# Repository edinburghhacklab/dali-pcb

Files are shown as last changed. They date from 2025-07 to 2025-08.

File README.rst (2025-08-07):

DALI PCB
========

Overview
--------

PCB to power and interface with DALI using an ESP32-S3.

Dimensions: 100mm W × 75mm H

Usage
-----

This is a KiCad project.

* `Software <https://github.com/edinburghhacklab/mqtt-dali-controller>`_

Schematics
----------

Power for the DALI bus is optional and can be connected using the solder jumper
bridges. If the power is supplied by this PCB then the polarity of the bus is
fixed so the bridge rectifier can be omitted.

Root schematic

DALI
~~~~

There are 2 DALI bus connections.

DALI schematic

Power
~~~~~

Power for the DALI bus is supplied by an external 12-22V DC power supply. Power
for the microcontroller is supplied by USB to the development board or an
external 5V DC power supply.

Power schematic

Microcontroller
~~~~~~~~~~~~~~~

Connect a `LOLIN S3  <https://www.wemos.cc/en/latest/s3/s3.html>`_ development
board to the pin sockets.

Microcontroller schematic

I/O
~~~

Analogue and digital I/O pin headers are provided for integrations with external
switches and rotary encoders.

The DALI bus also has a 3.3V direct pin header which can only be used when the
microcontroller is disconnected. This can't be used with a standard UART because
the DALI communication uses Manchester (bi-phase) encoding.

I/O schematic

PCB
---

* Internal bus power: populate JP1-2, and populate either JP3-4 or D5
* External bus power: populate D5, do not populate JP1-4

DALI PCB

Components
----------

+---------------------+----------+--------------------------------------------------------+
| Refs                | Quantity | Name                                                   |
+=====================+==========+========================================================+
|                     |     1    | LOLIN S3 Development Board                             |
+---------------------+----------+--------------------------------------------------------+
| D3                  |     1    | Diodes BAV99-7-F Dual Switching Diode, SOT-23-3        |
+---------------------+----------+--------------------------------------------------------+
| D4                  |     1    | Diodes DDZ9689S-7 Zener Diode, SOD-323                 |
+---------------------+----------+--------------------------------------------------------+
| D5                  |     1    | Infineon BGX50AE6327 Diode Bridge, SOT-143             |
+---------------------+----------+--------------------------------------------------------+
| J1, J2, J3, J4      |     4    | 1x02 Terminal Block, Through Hole (5.08mm)             |
+---------------------+----------+--------------------------------------------------------+
| J5, J6              |     2    | 1x20 Pin Socket, Through Hole (2.54mm)                 |
+---------------------+----------+--------------------------------------------------------+
| J7                  |     1    | 1x04 Pin Header, Through Hole (2.54mm)                 |
+---------------------+----------+--------------------------------------------------------+
| J8, J9              |     2    | 2x13 Pin Header, Through Hole (2.54mm)                 |
+---------------------+----------+--------------------------------------------------------+
| Q1                  |     1    | ON Semiconductor PZT2222AT1G NPN Transistor, SOT-223   |
+---------------------+----------+--------------------------------------------------------+
| Q2                  |     1    | ON Semiconductor MMBT2222ALT1G NPN Transistor, SOT-23  |
+---------------------+----------+--------------------------------------------------------+
| R2                  |     1    | 12Ω 1W Resistor, SMD 2512 (Metric 6332)                |
+---------------------+----------+--------------------------------------------------------+
| R3, R8              |     2    | 1kΩ 1W Resistor, SMD 2512 (Metric 6332)                |
+---------------------+----------+--------------------------------------------------------+
| R4                  |     1    | 120Ω 125mW Resistor, SMD 0805 (Metric 2012)            |
+---------------------+----------+--------------------------------------------------------+
| R5                  |     1    | 220Ω 125mW Resistor, SMD 0805 (Metric 2012)            |
+---------------------+----------+--------------------------------------------------------+
| R6                  |     1    | 2.2kΩ 250mW Resistor, SMD 1206 (Metric 3216)           |
+---------------------+----------+--------------------------------------------------------+
| R7                  |     1    | 10kΩ 125mW Resistor, SMD 0805 (Metric 2012)            |
+---------------------+----------+--------------------------------------------------------+
| U1, U2              |     2    | Vishay Semiconductors TCLT1000 Optocoupler, SOP-4L     |
+---------------------+----------+--------------------------------------------------------+

Total pin header count: 56

References
----------

* `Digitally Addressable Lighting Interface (DALI) Communication <https://ww1.microchip.com/downloads/en/AppNotes/01465A.pdf>`_

* `Digitally Addressable Lighting Interface (DALI) Unit Using the MC68HC908KX8 <https://www.nxp.com/docs/en/reference-manual/DRM004.pdf>`_

* `Digital Addressable Lighting Interface (DALI) Implementation Using MSP430 Value Line Microcontrollers <https://www.ti.com/lit/an/slaa422a/slaa422a.pdf>`_

* `DALI Communication Using the EFR32 <https://www.silabs.com/documents/public/application-notes/an1220-efr32-dali.pdf>`_

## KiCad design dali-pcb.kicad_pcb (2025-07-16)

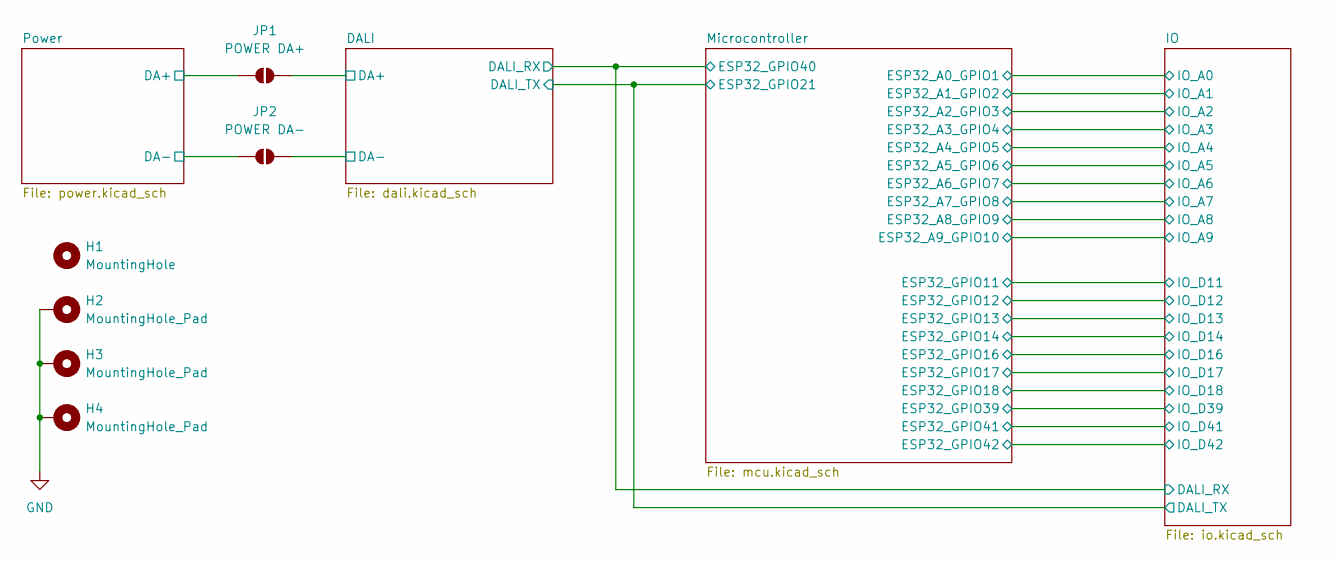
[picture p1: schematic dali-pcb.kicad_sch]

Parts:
H1: MountingHole; MountingHole_3.2mm_M3
H2, H3, H4: MountingHole_Pad; MountingHole_3.2mm_M3_Pad
JP1: POWER DA+; SolderJumper-2_P1.3mm_Open_RoundedPad1.0x1.5mm
JP2: POWER DA-; SolderJumper-2_P1.3mm_Open_RoundedPad1.0x1.5mm

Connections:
/DALI/DA+: JP1.1 (A); also elsewhere on the board
/DALI/DA-: JP2.2 (B); also elsewhere on the board
/Power/DA+: JP1.2 (B); also elsewhere on the board
/Power/DA-: JP2.1 (A); also elsewhere on the board
GND: H2.1, H3.1, H4.1; also elsewhere on the board

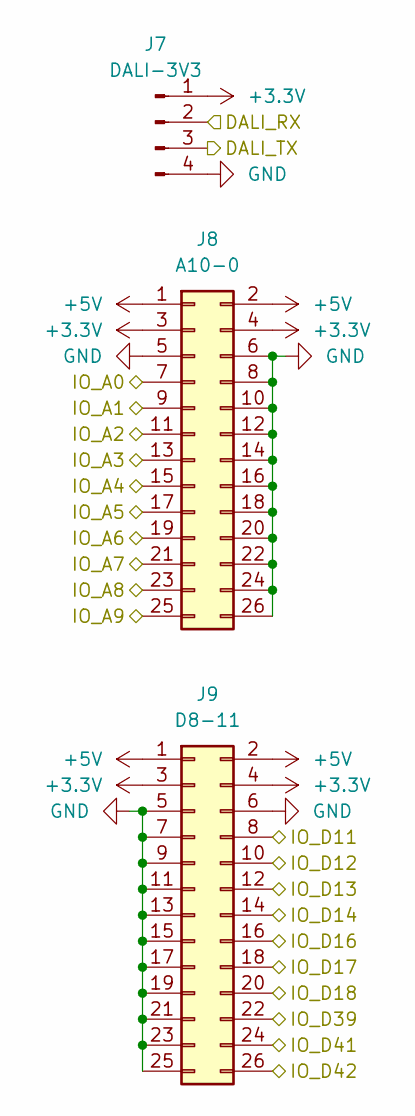
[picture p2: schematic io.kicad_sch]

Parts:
J7: DALI-3V3; PinHeader_1x04_P2.54mm_Vertical
J8: A10-0; PinHeader_2x13_P2.54mm_Vertical
J9: D8-11; PinHeader_2x13_P2.54mm_Vertical

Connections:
+3.3V: J7.1, J8.3, J8.4, J9.3, J9.4; also elsewhere on the board
+5V: J8.1, J8.2, J9.1, J9.2; also elsewhere on the board
/DALI/DALI_RX: J7.2; also elsewhere on the board
/DALI/DALI_TX: J7.3; also elsewhere on the board
/IO/IO_A0: J8.7; also elsewhere on the board
/IO/IO_A1: J8.9; also elsewhere on the board
/IO/IO_A2: J8.11; also elsewhere on the board
/IO/IO_A3: J8.13; also elsewhere on the board
/IO/IO_A4: J8.15; also elsewhere on the board
/IO/IO_A5: J8.17; also elsewhere on the board
/IO/IO_A6: J8.19; also elsewhere on the board
/IO/IO_A7: J8.21; also elsewhere on the board
/IO/IO_A8: J8.23; also elsewhere on the board
/IO/IO_A9: J8.25; also elsewhere on the board
/IO/IO_D11: J9.8; also elsewhere on the board
/IO/IO_D12: J9.10; also elsewhere on the board
/IO/IO_D13: J9.12; also elsewhere on the board
/IO/IO_D14: J9.14; also elsewhere on the board
/IO/IO_D16: J9.16; also elsewhere on the board
/IO/IO_D17: J9.18; also elsewhere on the board
/IO/IO_D18: J9.20; also elsewhere on the board
/IO/IO_D39: J9.22; also elsewhere on the board
/IO/IO_D41: J9.24; also elsewhere on the board
/IO/IO_D42: J9.26; also elsewhere on the board
GND: J7.4, J8.5, J8.6, J8.8, J8.10, J8.12, J8.14, J8.16, J8.18, J8.20, J8.22, J8.24, J8.26, J9.5, J9.6, J9.7, J9.9, J9.11, J9.13, J9.15, J9.17, J9.19, J9.21, J9.23, J9.25; also elsewhere on the board

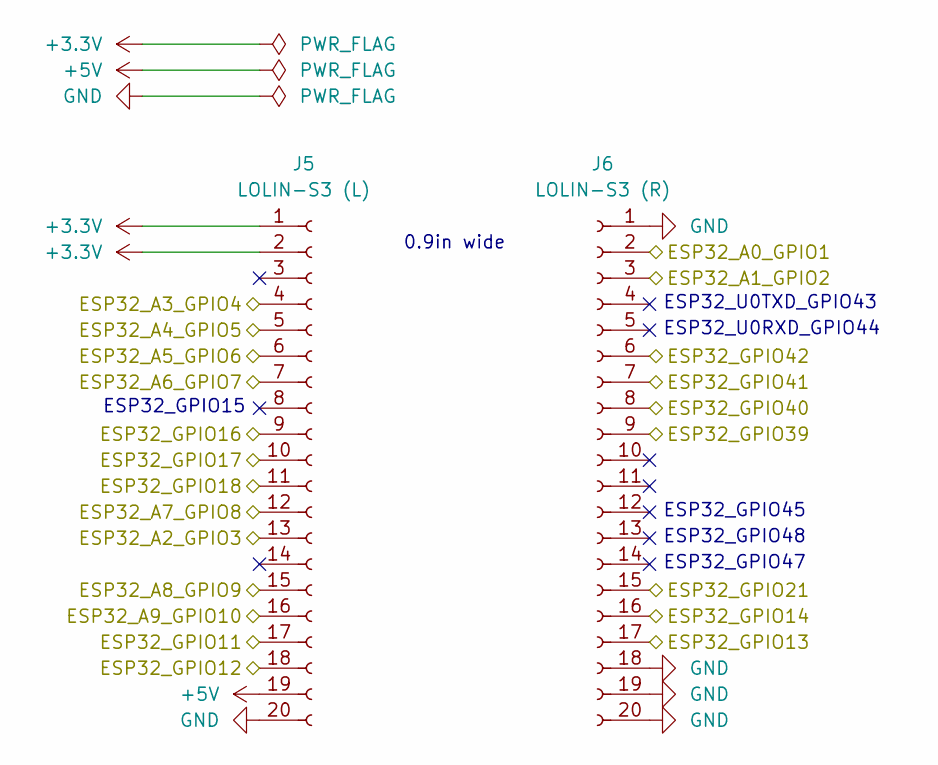
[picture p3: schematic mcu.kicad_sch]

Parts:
J5: LOLIN-S3 (L); PinSocket_1x20_P2.54mm_Vertical
J6: LOLIN-S3 (R); PinSocket_1x20_P2.54mm_Vertical

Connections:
+3.3V: J5.1, J5.2; also elsewhere on the board
+5V: J5.19; also elsewhere on the board
/DALI/DALI_RX: J6.8; also elsewhere on the board
/DALI/DALI_TX: J6.15; also elsewhere on the board
/IO/IO_A0: J6.2; also elsewhere on the board
/IO/IO_A1: J6.3; also elsewhere on the board
/IO/IO_A2: J5.13; also elsewhere on the board
/IO/IO_A3: J5.4; also elsewhere on the board
/IO/IO_A4: J5.5; also elsewhere on the board
/IO/IO_A5: J5.6; also elsewhere on the board
/IO/IO_A6: J5.7; also elsewhere on the board
/IO/IO_A7: J5.12; also elsewhere on the board
/IO/IO_A8: J5.15; also elsewhere on the board
/IO/IO_A9: J5.16; also elsewhere on the board
/IO/IO_D11: J5.17; also elsewhere on the board
/IO/IO_D12: J5.18; also elsewhere on the board
/IO/IO_D13: J6.17; also elsewhere on the board
/IO/IO_D14: J6.16; also elsewhere on the board
/IO/IO_D16: J5.9; also elsewhere on the board
/IO/IO_D17: J5.10; also elsewhere on the board
/IO/IO_D18: J5.11; also elsewhere on the board
/IO/IO_D39: J6.9; also elsewhere on the board
/IO/IO_D41: J6.7; also elsewhere on the board
/IO/IO_D42: J6.6; also elsewhere on the board
GND: J5.20, J6.1, J6.18, J6.19, J6.20; also elsewhere on the board

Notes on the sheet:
ESP32_U0TXD_GPIO43
ESP32_GPIO15
0.9in wide
ESP32_GPIO47
ESP32_GPIO45
ESP32_GPIO48
ESP32_U0RXD_GPIO44

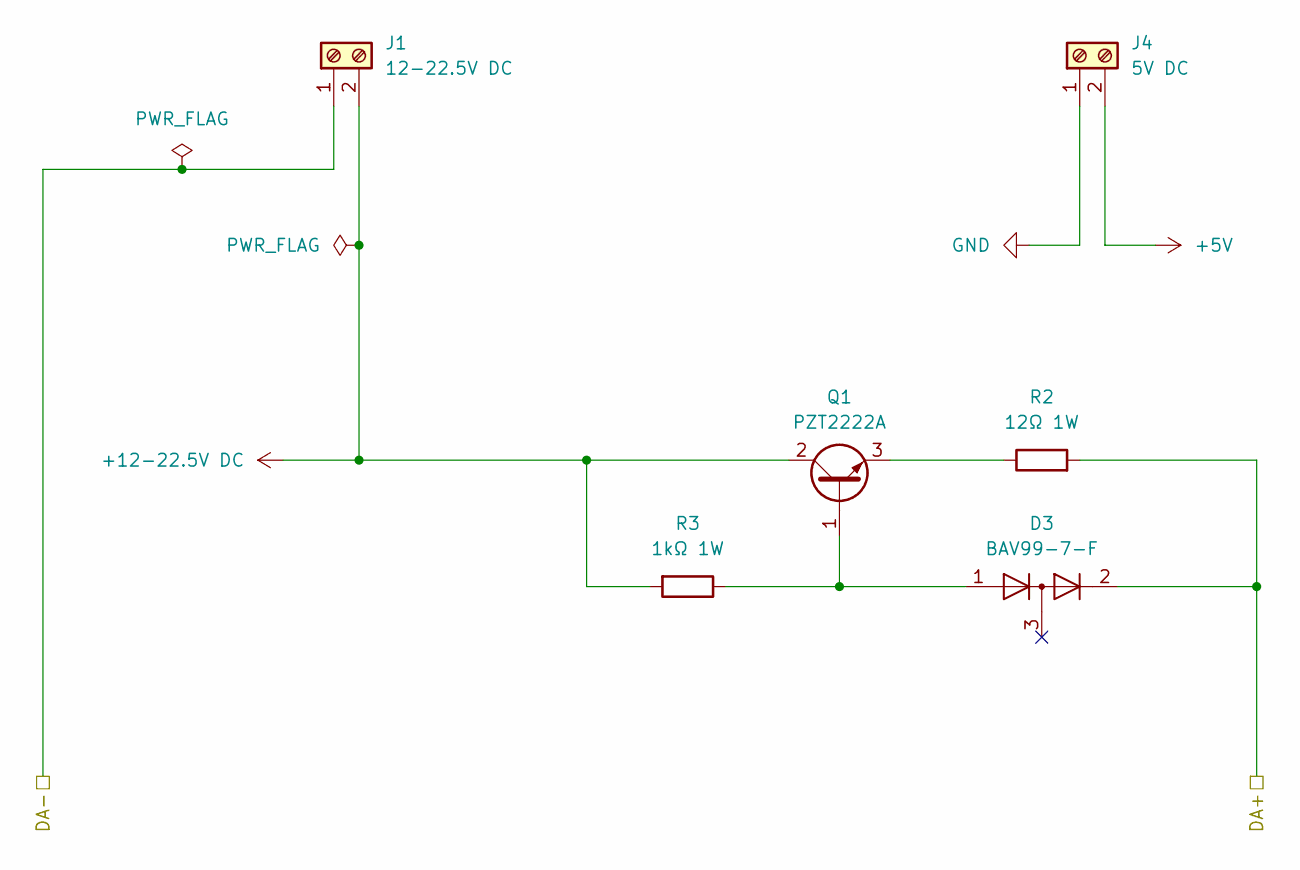
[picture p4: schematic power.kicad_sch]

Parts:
D3: BAV99-7-F; SOT-23_Handsoldering
J1: 12-22.5V DC; TerminalBlock_bornier-2_P5.08mm
J4: 5V DC; TerminalBlock_bornier-2_P5.08mm
Q1: PZT2222A; SOT-223-3_TabPin2
R2: 12Ω 1W; R_2512_6332Metric_Pad1.40x3.35mm_HandSolder
R3: 1kΩ 1W; R_2512_6332Metric_Pad1.40x3.35mm_HandSolder

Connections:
+5V: J4.2; also elsewhere on the board
+12-22.5V DC: J1.2, Q1.2 (C), R3.2
/Power/DA+: D3.2 (A), R2.2; also elsewhere on the board
/Power/DA-: J1.1; also elsewhere on the board
GND: J4.1; also elsewhere on the board
unnamed: D3.1 (K), Q1.1 (B), R3.1
unnamed: Q1.3 (E), R2.1

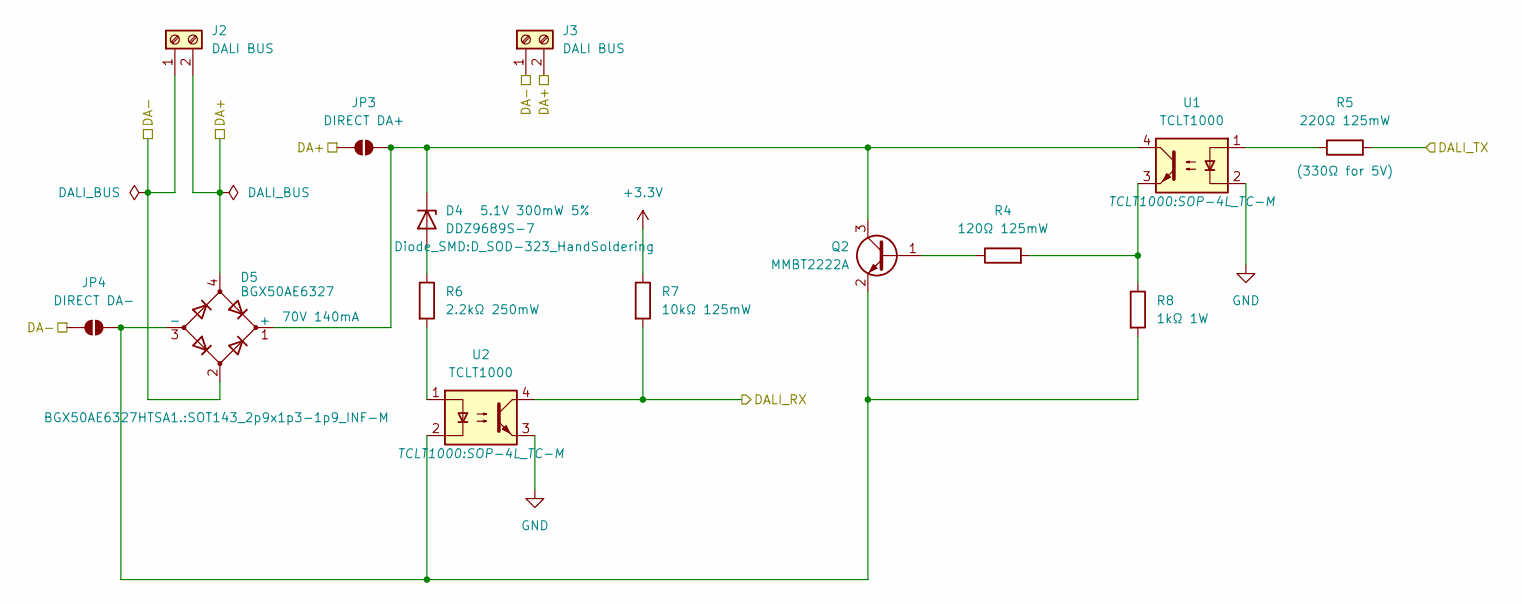
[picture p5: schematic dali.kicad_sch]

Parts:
D4: DDZ9689S-7; D_SOD-323_HandSoldering
D5: BGX50AE6327; SOT143_2p9x1p3-1p9_INF-M
J2, J3: DALI BUS; TerminalBlock_bornier-2_P5.08mm
JP3: DIRECT DA+; SolderJumper-2_P1.3mm_Open_RoundedPad1.0x1.5mm
JP4: DIRECT DA-; SolderJumper-2_P1.3mm_Open_RoundedPad1.0x1.5mm
Q2: MMBT2222A; SOT-23_Handsoldering
R4: 120Ω 125mW; R_0805_2012Metric_Pad1.20x1.40mm_HandSolder
R5: 220Ω 125mW; R_0805_2012Metric_Pad1.20x1.40mm_HandSolder
R6: 2.2kΩ 250mW; R_1206_3216Metric_Pad1.30x1.75mm_HandSolder
R7: 10kΩ 125mW; R_0805_2012Metric_Pad1.20x1.40mm_HandSolder
R8: 1kΩ 1W; R_2512_6332Metric_Pad1.40x3.35mm_HandSolder
U1, U2: TCLT1000; SOP-4L_TC-M

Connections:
+3.3V: R7.1; also elsewhere on the board
/DALI/DA+: D5.4, J2.2, J3.2, JP3.2 (B); also elsewhere on the board
/DALI/DA-: D5.2, J2.1, J3.1, JP4.2 (B); also elsewhere on the board
/DALI/DALI_RX: R7.2, U2.4; also elsewhere on the board
/DALI/DALI_TX: R5.2; also elsewhere on the board
GND: U1.2, U2.3; also elsewhere on the board
unnamed: D4.2 (A), R6.1
unnamed: D4.1 (K), D5.1 (+), JP3.1 (A), Q2.3 (C), U1.4
unnamed: D5.3 (-), JP4.1 (A), Q2.2 (E), R8.2, U2.2
unnamed: Q2.1 (B), R4.1
unnamed: R4.2, R8.1, U1.3
unnamed: R5.1, U1.1
unnamed: R6.2, U2.1

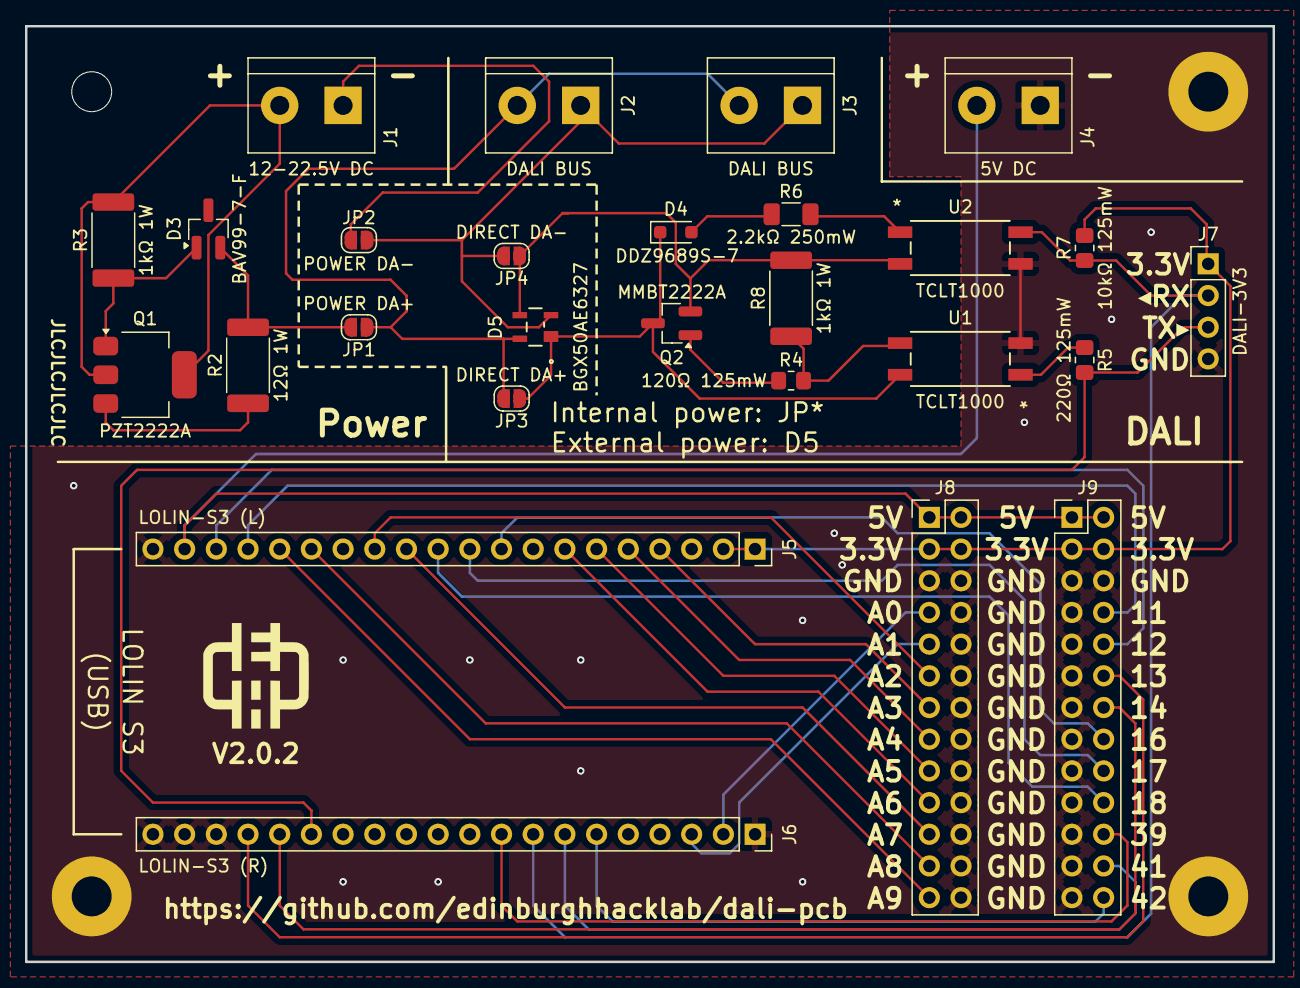
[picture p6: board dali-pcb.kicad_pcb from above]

Board: 2 copper layers, 100.0 x 75.0 mm, 32 parts (0 on the bottom side), 39 nets.

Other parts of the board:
EHLAB: LOGO

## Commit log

2025-07-08 Swap the order of the FTDI data pins
    [dali-pcb.kicad_sch]
2025-07-08 Rename UART pins to use Espressif convention
    [dali-pcb.kicad_sch, mcu.kicad_sch]
2025-07-08 The microcontroller can also be powered using USB
2025-07-08 Add an FTDI connector for the DALI bus
    [dali-pcb.kicad_sch, io.kicad_sch]
2025-07-08 Connect 5V from the FTDI connector to the DALI comms circuit
    [io.kicad_sch]
2025-07-08 Add individual two-pin switch I/O headers
    [io.kicad_sch]
2025-07-08 Assign footprints to resistors and use solder jumpers
    [dali-pcb.kicad_sch, dali.kicad_sch, power.kicad_sch]
2025-07-08 Assign footprints for the remaining components
    [dali.kicad_sch, io.kicad_sch, mcu.kicad_sch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]
2025-07-08 Update schematic for 3.3V and specify resistor power
    [dali.kicad_sch, power.kicad_sch]
2025-07-08 Place all components
    [dali-pcb.kicad_pcb, dali-pcb.kicad_sch, dali.kicad_sch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]
2025-07-08 Increase board size to protect the MCU USB connections
    [dali-pcb.kicad_pcb]
2025-07-08 Add +/- labels to screw terminals
    [dali-pcb.kicad_pcb]
2025-07-09 FTDI TTL-232R-3V3 can't be used to directly interface with DALI
    There's no 3.3V supply to use as a pull-up
    [dali-pcb.kicad_pcb, dali-pcb.kicad_sch, dali.kicad_sch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]
2025-07-09 Rotate R3 and improve silkscreen positions
    [dali-pcb.kicad_pcb, power.kicad_sch]
2025-07-09 Add LOLIN S3 mini support
    [dali-pcb.kicad_sch, mcu.kicad_sch, power.kicad_sch]
2025-07-09 Renumber references and place LOLIN-S3-MINI
    [dali-pcb.kicad_pcb, dali.kicad_sch, io.kicad_sch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]
2025-07-09 Add logo, URLs, version
    [dali-pcb.kicad_pcb]
2025-07-09 Render PCB
    [dali-pcb.kicad_pcb, mcu.kicad_sch]
2025-07-09 Move LOLIN mini boards further away from FTDI/UART pin headers
    [dali-pcb.kicad_pcb]
2025-07-09 Don't connect unused GPIOs together across MCUs
    [dali-pcb.kicad_pcb, dali-pcb.kicad_sch, mcu.kicad_sch]
2025-07-09 Label all the I/O pins
    [dali-pcb.kicad_pcb, io.kicad_sch]
2025-07-09 Fix screw terminal orientation and mounting holes
    [dali-pcb.kicad_pcb, dali.kicad_sch, power.kicad_sch]
2025-07-09 Add easy MCU traces and all the analogue I/O internal traces
    [dali-pcb.kicad_pcb]
2025-07-09 First routing attempt
    [dali-pcb.kicad_pcb, dali-pcb.kicad_sch, mcu.kicad_sch]
2025-07-09 Swap order of microcontrollers to avoid a mess of tracks
    [dali-pcb.kicad_pcb]
2025-07-09 Second routing attempt
    [dali-pcb.kicad_pcb]
2025-07-09 Everything is now connected
    [dali-pcb.kicad_pcb]
2025-07-10 Add more vias to reduce GND islands
    [dali-pcb.kicad_pcb]
2025-07-10 Add solder jumpers to bypass the bridge rectifier
    [dali-pcb.kicad_pcb, dali.kicad_sch]
2025-07-10 Reduce root schematic page size
    [dali-pcb.kicad_sch]
2025-07-10 Move power instructions to the PCB section
2025-07-10 Add more silkscreen to explain where things are
    [dali-pcb.kicad_pcb]
2025-07-10 Fix ESP32-S3-DEVKITC-1 bottom right pins
    [dali-pcb.kicad_pcb, dali.kicad_sch, mcu.kicad_sch]
2025-07-10 Check and list components
    [dali-pcb.kicad_pcb, dali.kicad_sch, power.kicad_sch]
2025-07-10 Move D5/JP3/JP4 to improve silkscreen position
    [dali-pcb.kicad_pcb]
2025-07-10 Reword bus power options
    [dali-pcb.kicad_pcb]
2025-07-10 Add JLC text
    [dali-pcb.kicad_pcb]
2025-07-11 Remove the kitchen sink
    [dali-pcb.kicad_pcb, dali-pcb.kicad_sch, dali.kicad_sch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]
2025-07-11 Fix indirect track route from Q2 to R8 via U2
    [dali-pcb.kicad_pcb]
2025-07-11 Fix pin header count
2025-07-11 Fix indirect track route from JP4 to R8 via Q2
    [dali-pcb.kicad_pcb]
2025-07-11 Move J7 further away from the edge of the PCB and realign R5/R7
    [dali-pcb.kicad_pcb]
2025-07-11 Show distance between bottom edge of PCB and I/O pin headers
    [dali-pcb.kicad_pcb]
2025-07-11 Fix other measurement positions
    [dali-pcb.kicad_pcb]
2025-07-11 Rename the UART connection to DIRECT because it needs Manchester encoding
    [dali-pcb.kicad_pcb, dali-pcb.kicad_sch, io.kicad_sch]
2025-07-11 Avoid using the name "DIRECT" in two places with different meanings
    [dali-pcb.kicad_pcb, io.kicad_sch]
2025-07-12 Remove dash
    [dali-pcb.kicad_pcb]
2025-07-12 Restore missing tracks
    [dali-pcb.kicad_pcb]
2025-07-12 Tidy up DALI_TX connection
    [dali-pcb.kicad_pcb]
2025-07-13 Add 3D models for D5, U1 and U2
    [dali-pcb.kicad_pcb]
2025-07-16 Remove connection between J1 (1) and GND
    [dali-pcb.kicad_pcb, dali-pcb.kicad_sch, power.kicad_sch]
2025-07-16 Remove filled GND zone from under the DALI power/bus components
    [dali-pcb.kicad_pcb, dali-pcb.kicad_sch]
